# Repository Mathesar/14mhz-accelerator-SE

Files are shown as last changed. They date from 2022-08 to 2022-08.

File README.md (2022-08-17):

# 14mhz-accelerator-SE
Special Edition of the 14MHz accelerator without local fastram and support for DMA masters

This version was especially created for owners of SCSI sidecars like the A590. 
It should support the DMA transfers of these sidecars.
This version also does away with the local 14MHz FAST RAM to reduce cost. 
Finally, this version uses the DIP version 68000 so one can retry overclocking the original CPU to make the design even cheaper.

IMPORTANT NOTE:
This design is UNTESTED AT THIS POINT. Use entirely at your own risk and have fun while doing so!

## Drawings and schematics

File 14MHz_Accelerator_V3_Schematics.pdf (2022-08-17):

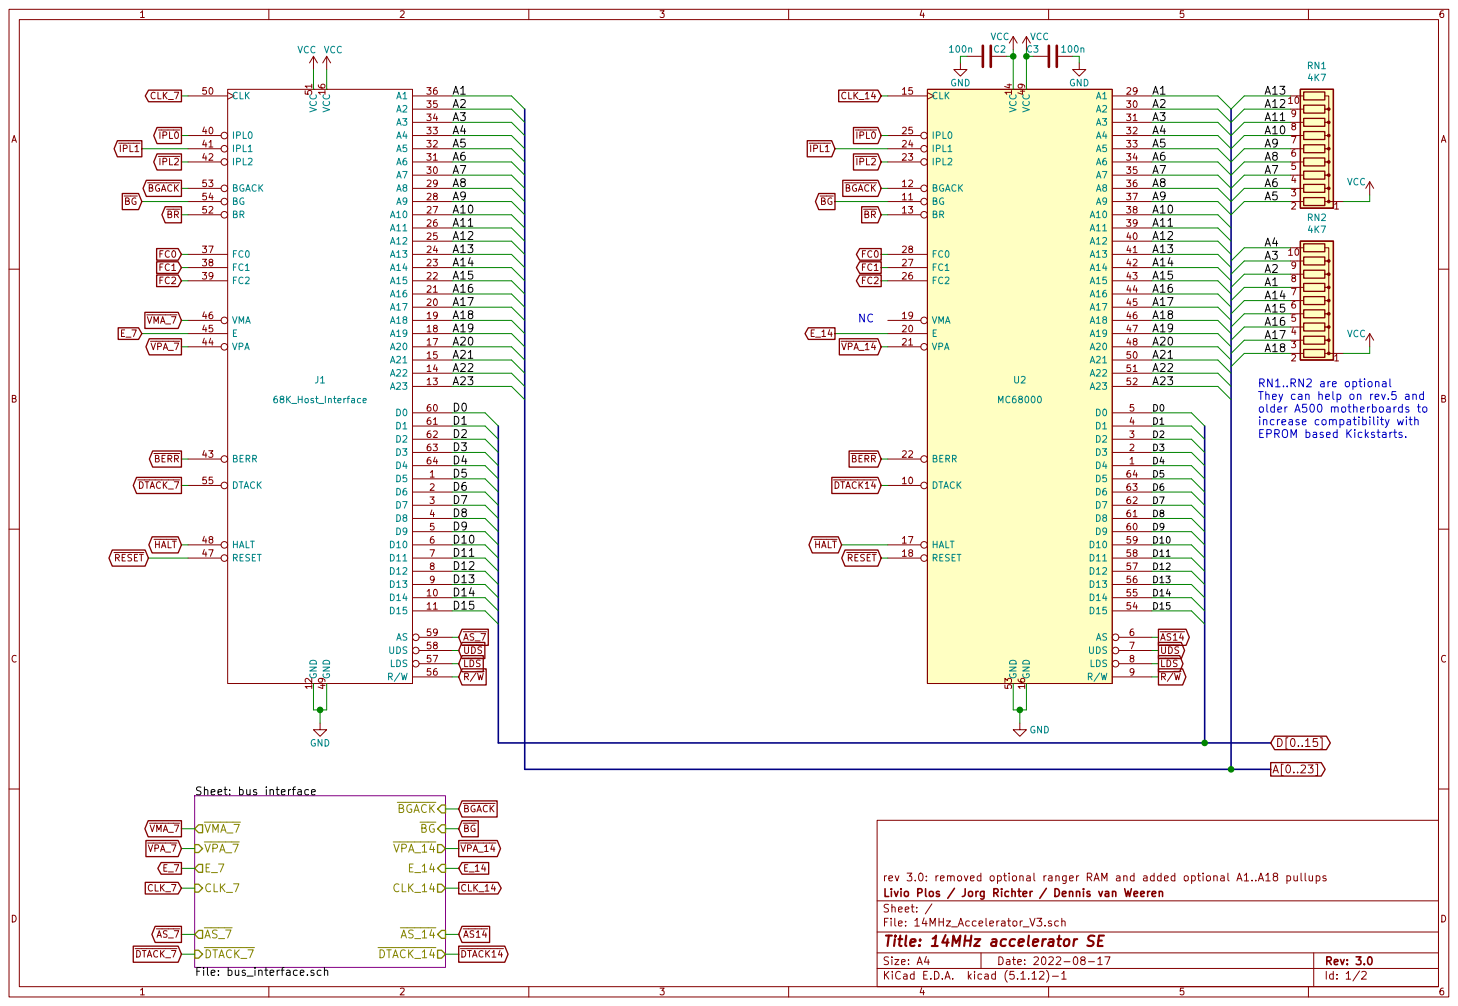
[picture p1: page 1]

RN1..RN2 are optional
They can help on rev.5 and older A500 motherboards to

rev 3.0: removed optional ranger RAM and added optional A1..A18 pullups
File: 14MHz_Accelerator_V3.sch Sheet: / Livio Plos / Jorg Richter / Dennis van Weeren

Id: 1/2 Title: 14MHz accelerator SE

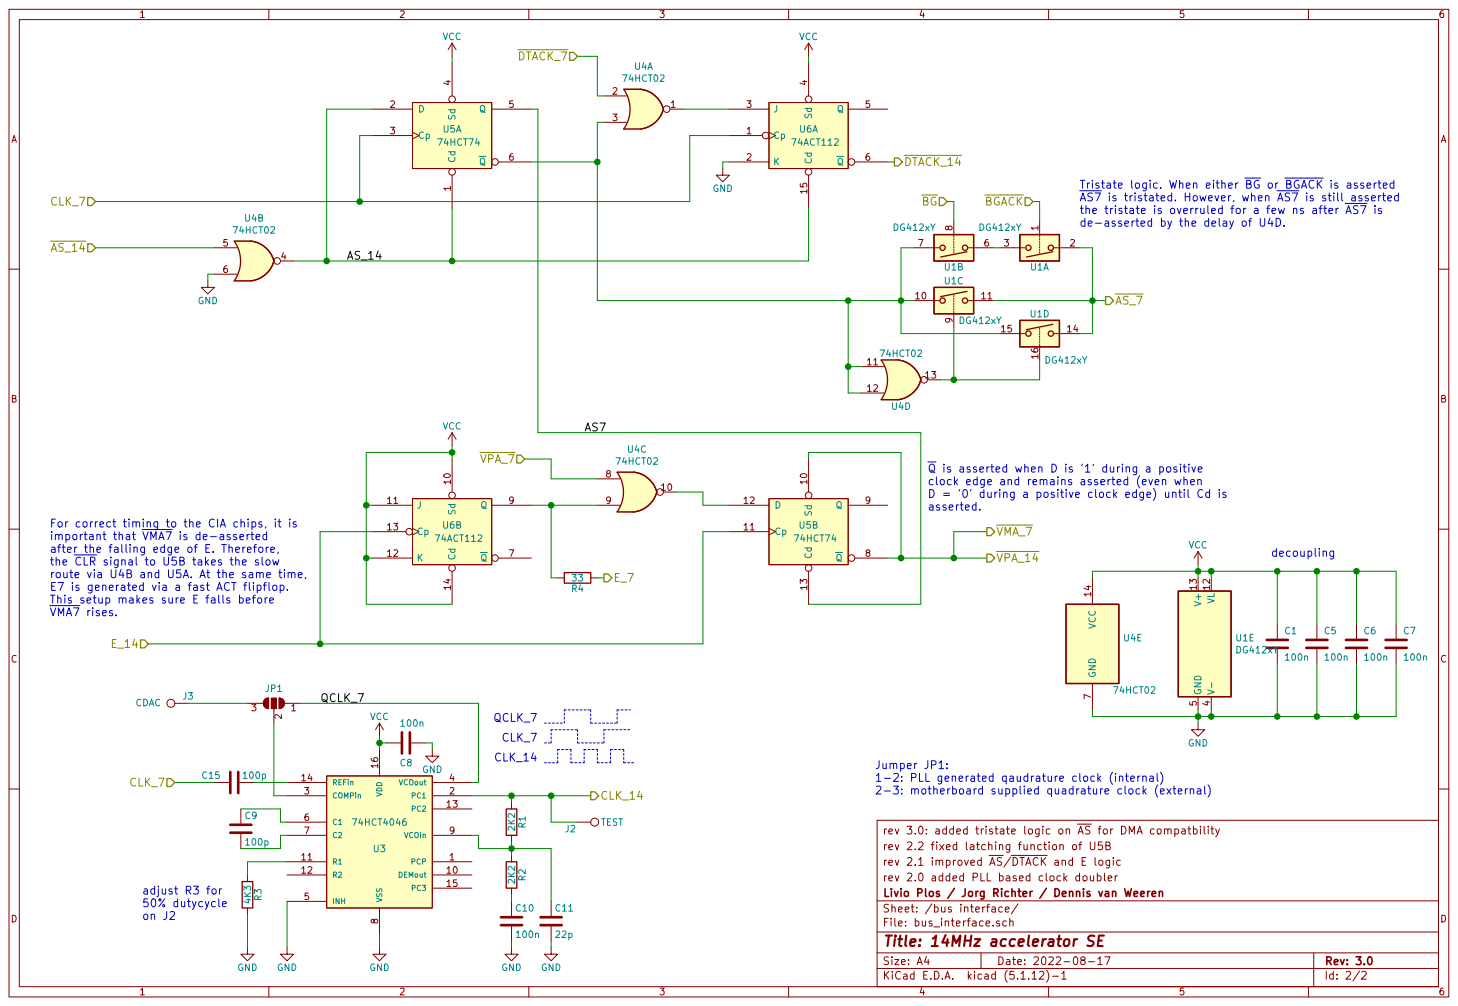
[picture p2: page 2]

Tristate logic. When either BG or BGACK is asserted
AS7 is tristated. However, when AS7 is still asserted
the tristate is overruled for a few ns after AS7 is
de-asserted by the delay of U4D.

Q is asserted when D is '1' during a positive
clock edge and remains asserted (even when
D = '0' during a positive clock edge) until Cd is asserted.

For correct timing to the CIA chips, it is
important that VMA7 is de-asserted
after the falling edge of E. Therefore,
the CLR signal to U5B takes the slow
route via U4B and U5A. At the same time,
E7 is generated via a fast ACT flipflop.

Jumper JP1:
1-2: PLL generated qaudrature clock (internal)
2-3: motherboard supplied quadrature clock (external)

rev 2.2 fixed latching function of U5B
rev 2.1 improved AS/DTACK and E logic
rev 2.0 added PLL based clock doubler
File: bus_interface.sch Sheet: /bus interface/ Livio Plos / Jorg Richter / Dennis van Weeren

Id: 2/2 Title: 14MHz accelerator SE

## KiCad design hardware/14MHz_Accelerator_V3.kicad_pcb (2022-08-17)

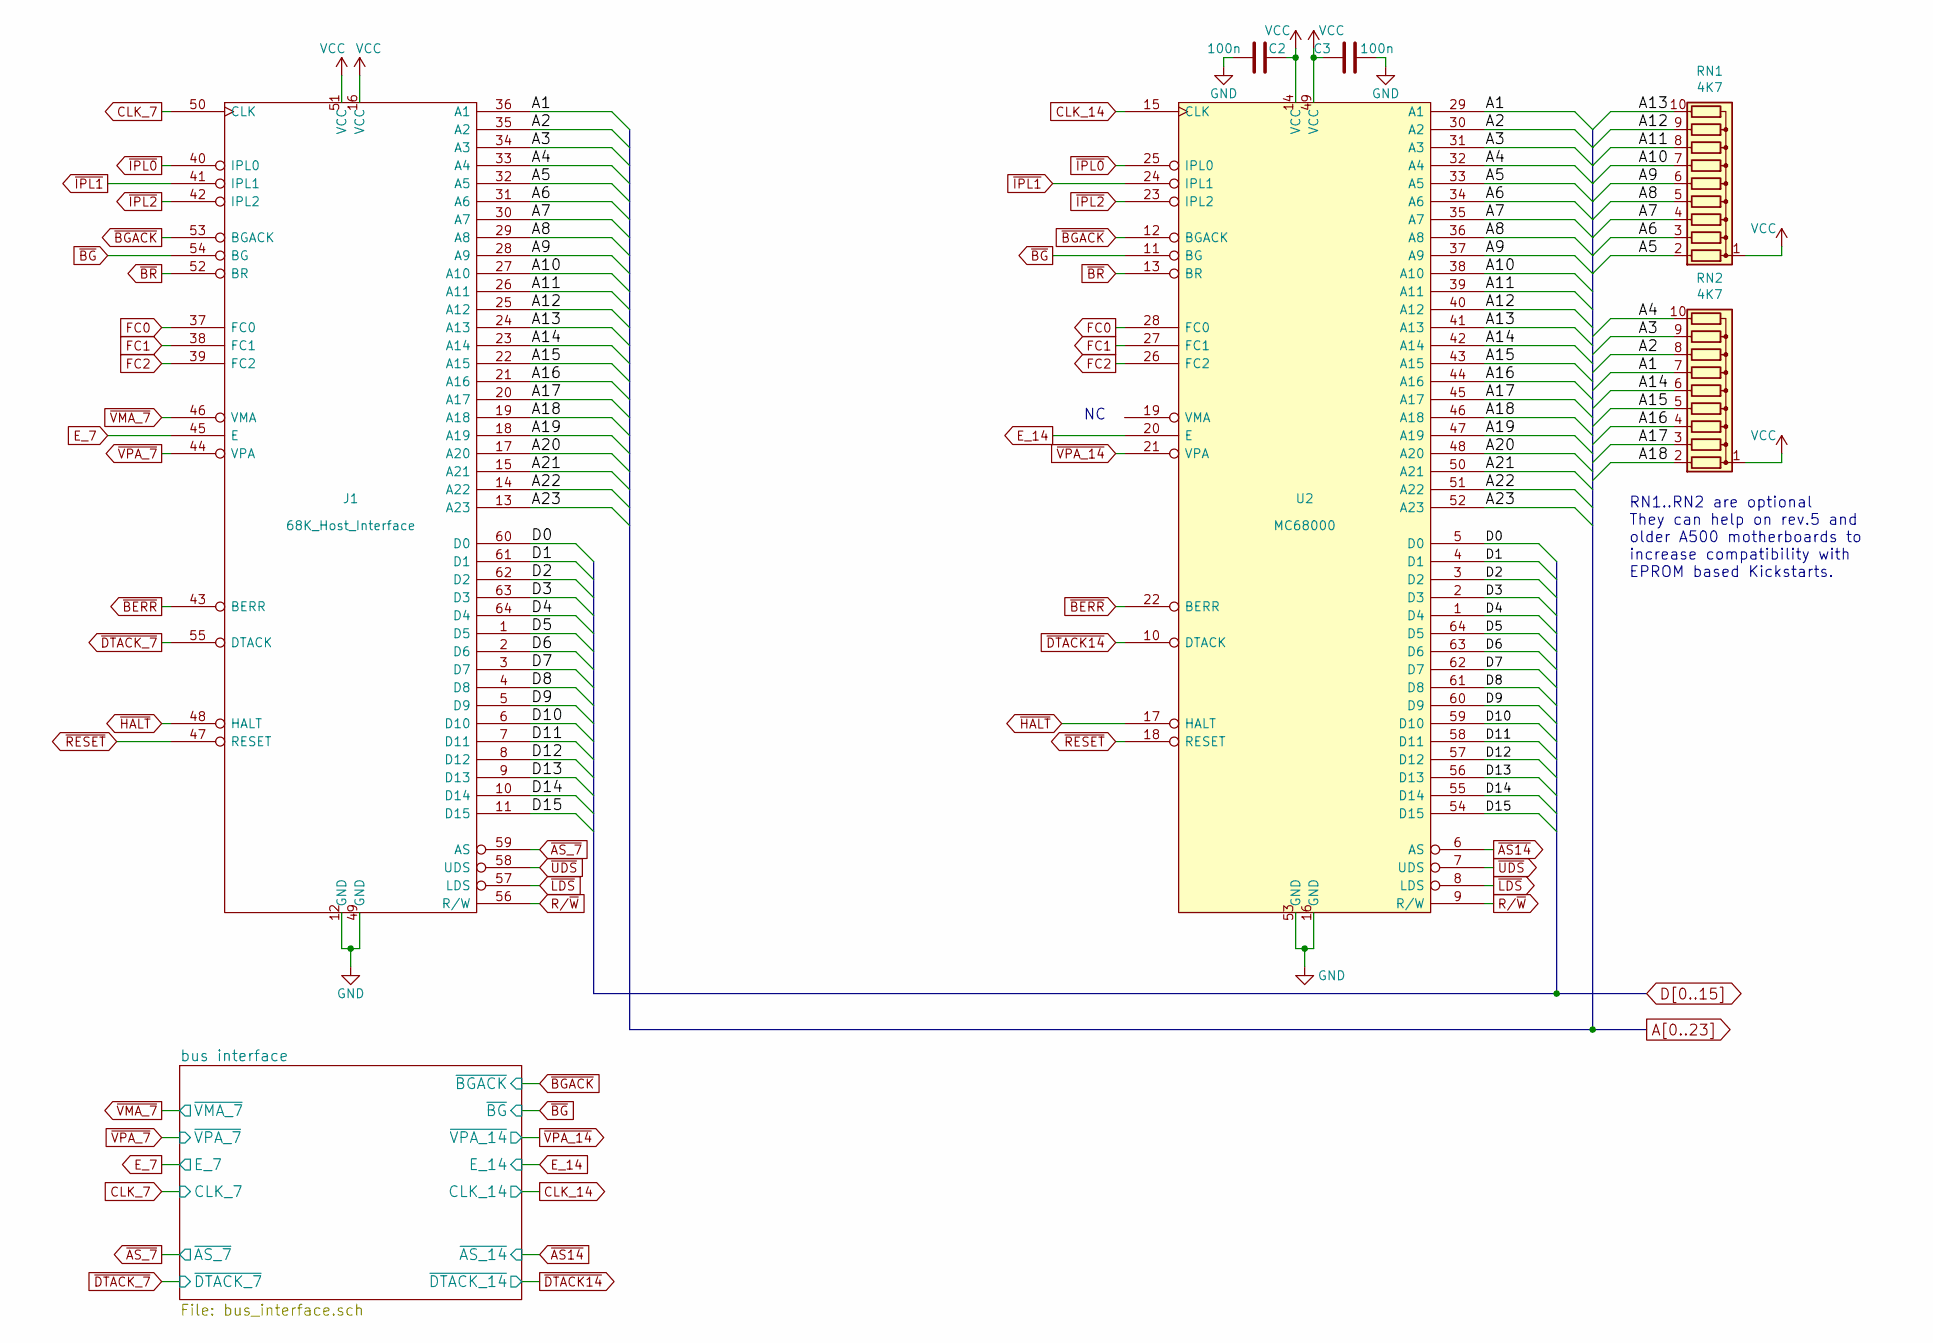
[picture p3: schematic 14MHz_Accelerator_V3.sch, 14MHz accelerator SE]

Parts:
C2, C3: 100n; C_0805_HandSoldering
J1: 68K_Host_Interface; DIP-64_W22.86mm
RN1, RN2: 4K7; R_Array_SIP10
U2: MC68000; DIP-64_W22.86mm

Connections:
A1: J1.36 (A1), RN2.7 (R6), U2.29 (A1)
A2: J1.35 (A2), RN2.8 (R7), U2.30 (A2)
A3: J1.34 (A3), RN2.9 (R8), U2.31 (A3)
A4: J1.33 (A4), RN2.10 (R9), U2.32 (A4)
A5: J1.32 (A5), RN1.2 (R1), U2.33 (A5)
A6: J1.31 (A6), RN1.3 (R2), U2.34 (A6)
A7: J1.30 (A7), RN1.4 (R3), U2.35 (A7)
A8: J1.29 (A8), RN1.5 (R4), U2.36 (A8)
A9: J1.28 (A9), RN1.6 (R5), U2.37 (A9)
A10: J1.27 (A10), RN1.7 (R6), U2.38 (A10)
A11: J1.26 (A11), RN1.8 (R7), U2.39 (A11)
A12: J1.25 (A12), RN1.9 (R8), U2.40 (A12)
A13: J1.24 (A13), RN1.10 (R9), U2.41 (A13)
A14: J1.23 (A14), RN2.6 (R5), U2.42 (A14)
A15: J1.22 (A15), RN2.5 (R4), U2.43 (A15)
A16: J1.21 (A16), RN2.4 (R3), U2.44 (A16)
A17: J1.20 (A17), RN2.3 (R2), U2.45 (A17)
A18: J1.19 (A18), RN2.2 (R1), U2.46 (A18)
A19: J1.18 (A19), U2.47 (A19)
A20: J1.17 (A20), U2.48 (A20)
A21: J1.15 (A21), U2.50 (A21)
A22: J1.14 (A22), U2.51 (A22)
A23: J1.13 (A23), U2.52 (A23)
CLK_7: J1.50 (CLK); also elsewhere on the board
CLK_14: U2.15 (CLK); also elsewhere on the board
D0: J1.60 (D0), U2.5 (D0)
D1: J1.61 (D1), U2.4 (D1)
D2: J1.62 (D2), U2.3 (D2)
D3: J1.63 (D3), U2.2 (D3)
D4: J1.64 (D4), U2.1 (D4)
D5: J1.1 (D5), U2.64 (D5)
D6: J1.2 (D6), U2.63 (D6)
D7: J1.3 (D7), U2.62 (D7)
D8: J1.4 (D8), U2.61 (D8)
D9: J1.5 (D9), U2.60 (D9)
D10: J1.6 (D10), U2.59 (D10)
D11: J1.7 (D11), U2.58 (D11)
D12: J1.8 (D12), U2.57 (D12)
D13: J1.9 (D13), U2.56 (D13)
D14: J1.10 (D14), U2.55 (D14)
D15: J1.11 (D15), U2.54 (D15)
E_7: J1.45 (E); also elsewhere on the board
E_14: U2.20 (E); also elsewhere on the board
FC0: J1.37 (FC0), U2.28 (FC0)
FC1: J1.38 (FC1), U2.27 (FC1)
FC2: J1.39 (FC2), U2.26 (FC2)
GND: C2.1, C3.2, J1.12 (GND), J1.49 (GND), U2.16 (GND), U2.53 (GND); also elsewhere on the board
R/~W: J1.56 (R/W), U2.9 (R/W)
VCC: C2.2, C3.1, J1.16 (VCC), J1.51 (VCC), RN1.1 (common), RN2.1 (common), U2.14 (VCC), U2.49 (VCC); also elsewhere on the board
~AS14: U2.6 (AS); also elsewhere on the board
~AS_7: J1.59 (AS); also elsewhere on the board
~BERR~: J1.43 (BERR), U2.22 (BERR)
~BGACK~: J1.53 (BGACK), U2.12 (BGACK); also elsewhere on the board
~BG~: J1.54 (BG), U2.11 (BG); also elsewhere on the board
~BR~: J1.52 (BR), U2.13 (BR)
~DTACK14: U2.10 (DTACK); also elsewhere on the board
~DTACK_7: J1.55 (DTACK); also elsewhere on the board
~HALT~: J1.48 (HALT), U2.17 (HALT)
~IPL0~: J1.40 (IPL0), U2.25 (IPL0)
~IPL1~: J1.41 (IPL1), U2.24 (IPL1)
~IPL2~: J1.42 (IPL2), U2.23 (IPL2)
~LDS: J1.57 (LDS), U2.8 (LDS)
~RESET~: J1.47 (RESET), U2.18 (RESET)
~UDS: J1.58 (UDS), U2.7 (UDS)
~VMA_7: J1.46 (VMA), U2.21 (VPA); also elsewhere on the board
~VPA_7: J1.44 (VPA); also elsewhere on the board

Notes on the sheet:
RN1..RN2 are optional They can help on rev.5 and older A500 motherboards to increase compatibility with EPROM based Kickstarts.

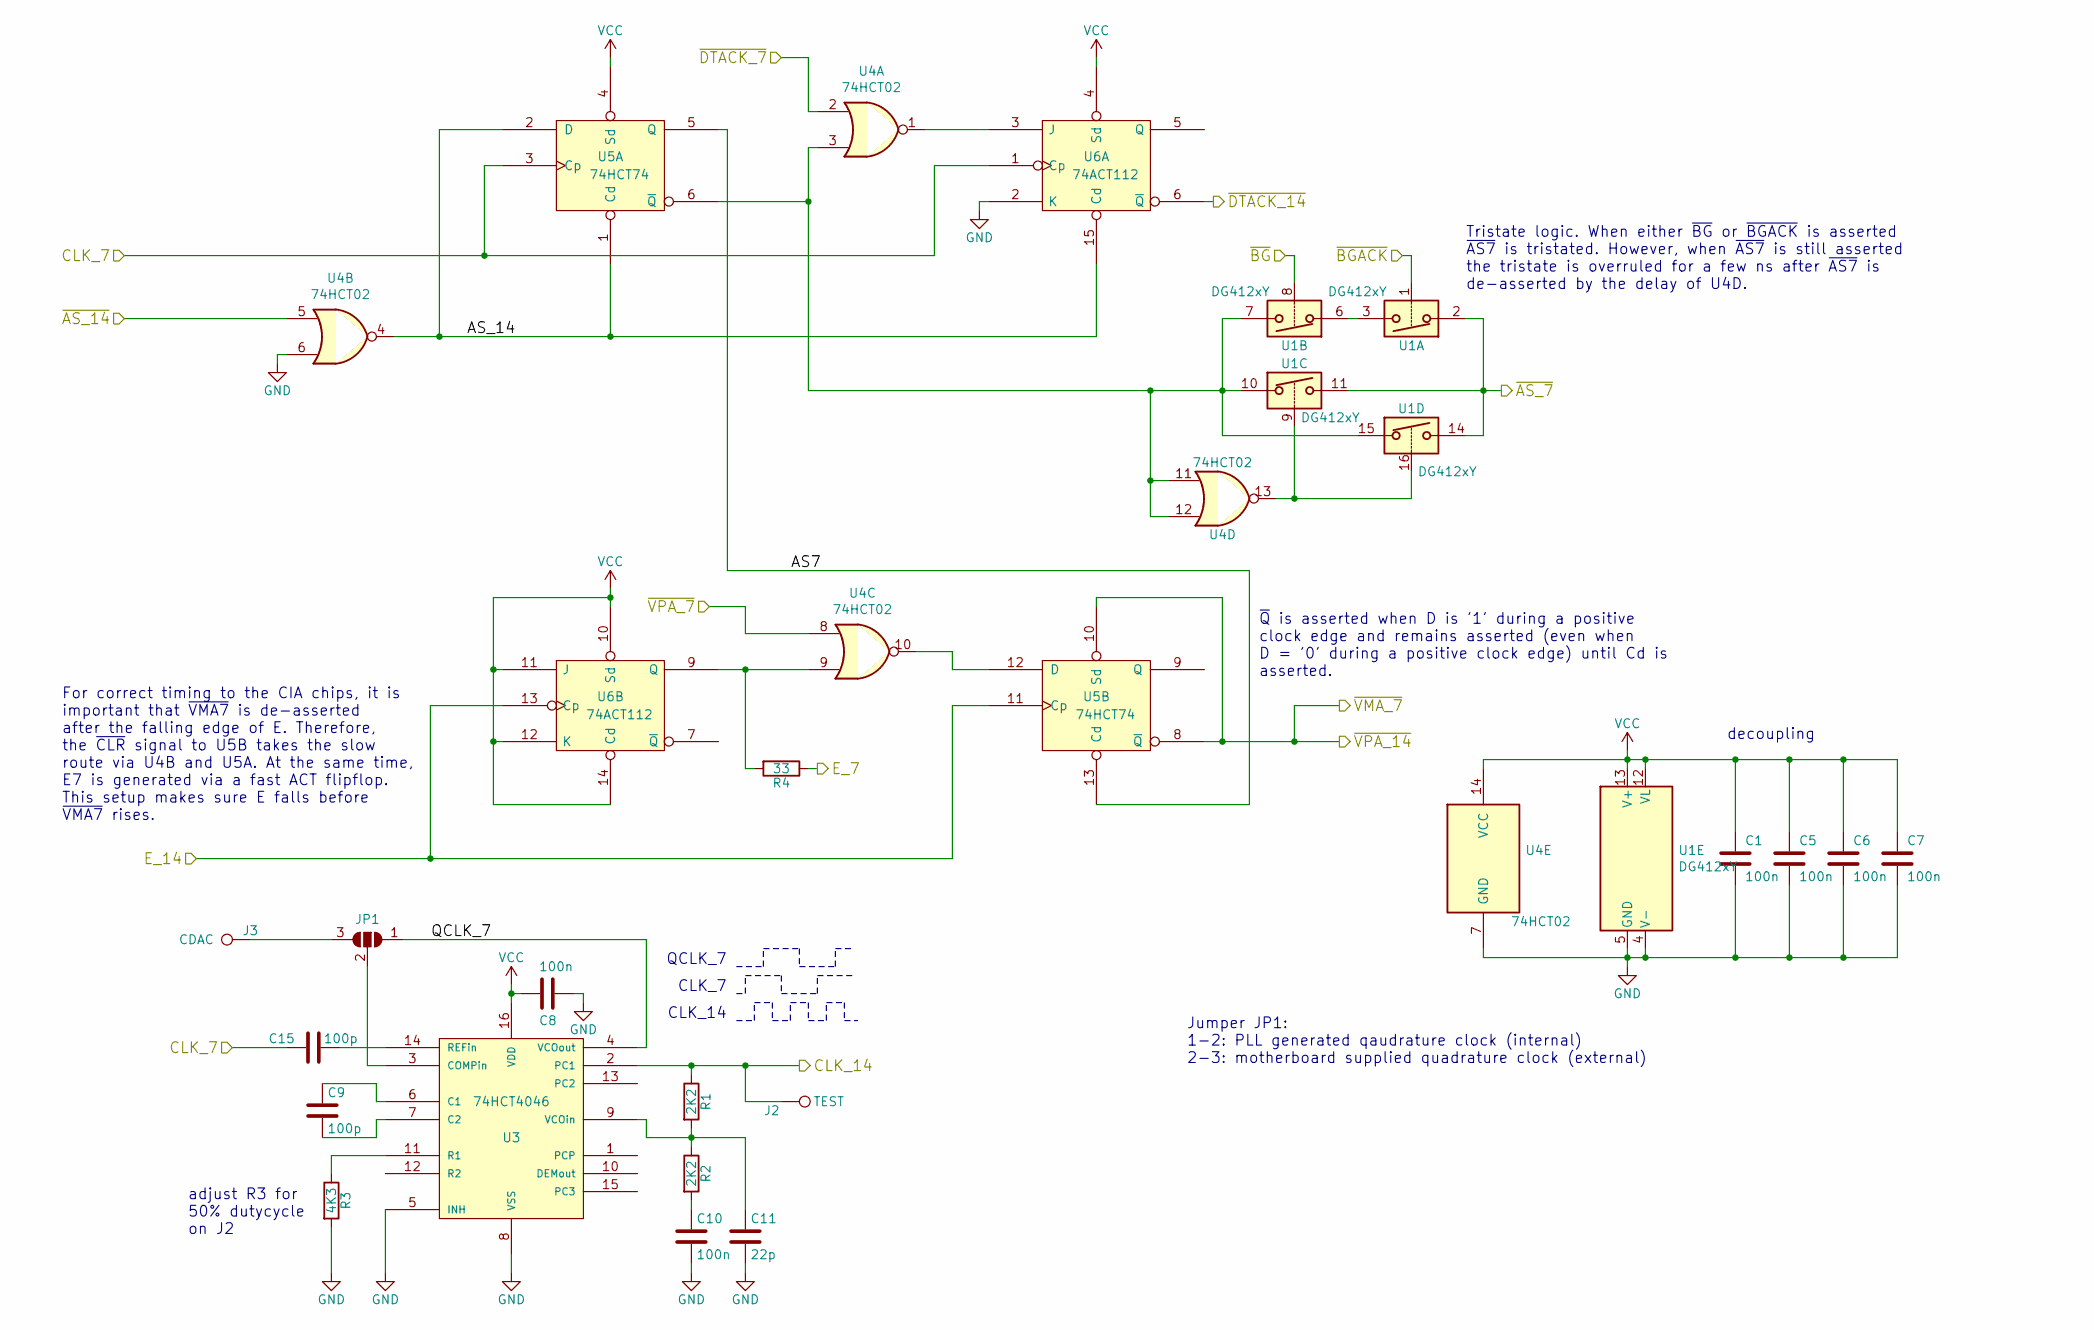
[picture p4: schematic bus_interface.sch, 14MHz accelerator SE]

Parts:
C1, C5, C6, C7, C8, C10: 100n; C_0805_HandSoldering
C9, C15: 100p; C_0805_HandSoldering
C11: 22p; C_0805_HandSoldering
J2: TEST; Pin_d1.0mm_L10.0mm
J3: CDAC; Pin_d1.0mm_L10.0mm
JP1: SolderJumper_3_Open; GS3
R1, R2: 2K2; R_0805_HandSoldering
R3: 4K3; R_0805_HandSoldering
R4: 33; R_0805_HandSoldering
U1: DG412xY; SOIC-16_3.9x9.9mm_P1.27mm
U3: 74HCT4046; SOIC-16_3.9x9.9mm_Pitch1.27mm
U4: 74HCT02; SOIC-14_3.9x8.7mm_Pitch1.27mm
U5: 74HCT74; SOIC-14_3.9x8.7mm_Pitch1.27mm
U6: 74ACT112; SOIC-16_3.9x9.9mm_Pitch1.27mm

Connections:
/bus interface/AS7: U5.5 (Q), U5.13 (Cd)
/bus interface/AS_14: U4.4, U5.1 (Cd), U5.2 (D), U6.15 (Cd)
/bus interface/QCLK_7: JP1.1 (A), U3.4 (VCOout)
CLK_7: C15.1, U5.3 (Cp), U6.1 (Cp); also elsewhere on the board
CLK_14: J2.1, R1.1, U3.2 (PC1); also elsewhere on the board
E_7: R4.1; also elsewhere on the board
E_14: U5.11 (Cp), U6.13 (Cp); also elsewhere on the board
GND: C1.2, C5.2, C6.2, C7.2, C8.1, C10.2, C11.2, R3.2, U1.4 (V-), U1.5 (GND), U3.5 (INH), U3.8 (VSS), U4.6, U4.7 (GND), U5.7 (GND), U6.2 (K), U6.8 (GND); also elsewhere on the board
unnamed: C9.1, U3.6 (C1)
unnamed: C9.2, U3.7 (C2)
unnamed: C10.1, R2.2
unnamed: C11.1, R1.2, R2.1, U3.9 (VCOin)
unnamed: C15.2, U3.14 (REFin)
unnamed: J3.1, JP1.3 (B)
unnamed: JP1.2 (C), U3.3 (COMPin)
unnamed: R3.1, U3.11 (R1)
unnamed: R4.2, U4.9, U6.9 (Q)
unnamed: U1.3, U1.6
unnamed: U1.7, U1.10, U1.15, U4.3, U4.11, U4.12, U5.6 (~Q)
unnamed: U1.9, U1.16, U4.13
unnamed: U4.1, U6.3 (J)
unnamed: U4.10, U5.12 (D)
VCC: C1.1, C5.1, C6.1, C7.1, C8.2, U1.12 (VL), U1.13 (V+), U3.16 (VDD), U4.14 (VCC), U5.4 (Sd), U5.14 (VCC), U6.4 (Sd), U6.10 (Sd), U6.11 (J), U6.12 (K), U6.14 (Cd), U6.16 (VCC); also elsewhere on the board
~AS14: U4.5; also elsewhere on the board
~AS_7: U1.2, U1.11, U1.14; also elsewhere on the board
~BGACK~: U1.1; also elsewhere on the board
~BG~: U1.8; also elsewhere on the board
~DTACK14: U6.6 (~Q); also elsewhere on the board
~DTACK_7: U4.2; also elsewhere on the board
~VMA_7: U5.8 (~Q), U5.10 (Sd); also elsewhere on the board
~VPA_7: U4.8; also elsewhere on the board

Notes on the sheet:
CLK_7
CLK_14
QCLK_7
adjust R3 for 50% dutycycle on J2
~Q~ is asserted when D is '1' during a positive clock edge and remains asserted (even when D = '0' during a positive clock edge) until Cd is asserted.
Jumper JP1: 1-2: PLL generated qaudrature clock (internal) 2-3: motherboard supplied quadrature clock (external)
For correct timing to the CIA chips, it is important that ~VMA7~ is de-asserted after the falling edge of E. Therefore, the ~CLR~ signal to U5B takes the slow route via U4B and U5A. At the same time, E7 is generated via a fast ACT flipflop. This setup makes sure E falls before ~VMA7~ rises.
Tristate logic. When either ~BG~ or ~BGACK~ is asserted ~AS7~ is tristated. However, when ~AS7~ is still asserted the tristate is overruled for a few ns after ~AS7~ is de-asserted by the delay of U4D.
decoupling

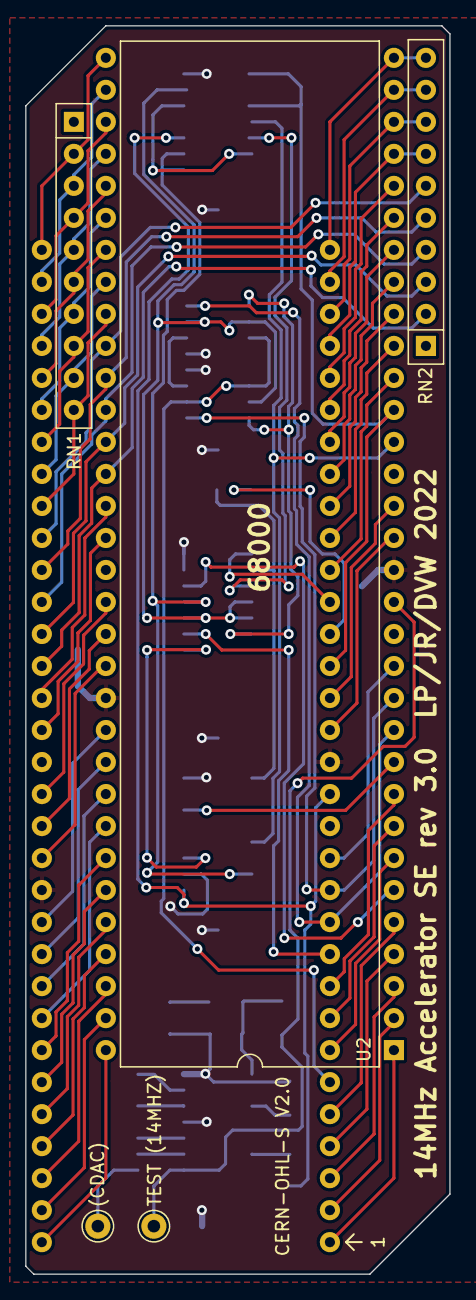
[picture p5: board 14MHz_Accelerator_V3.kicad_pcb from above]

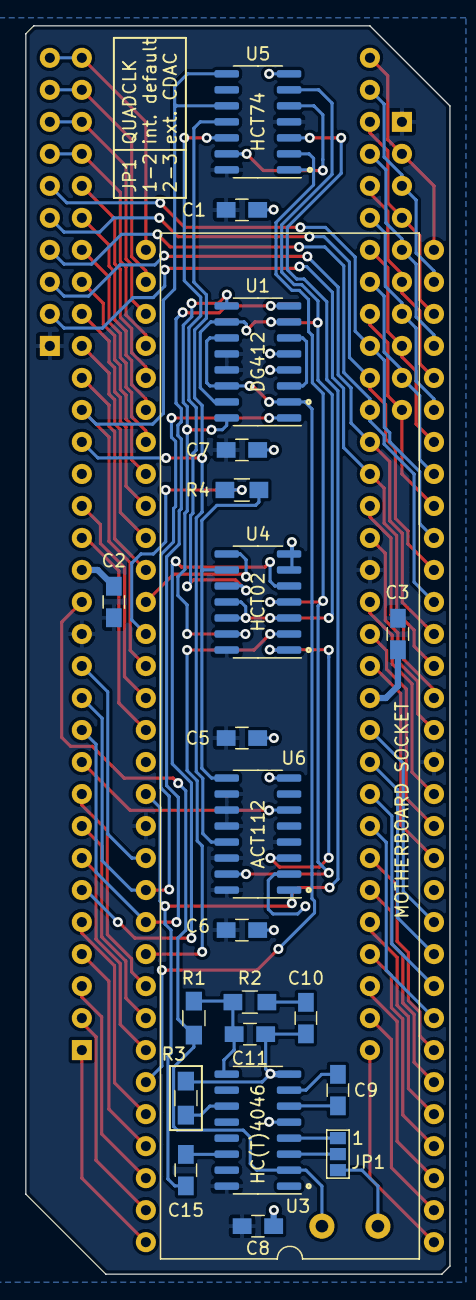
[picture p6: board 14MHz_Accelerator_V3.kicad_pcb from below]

Board: 2 copper layers, 33.7 x 99.1 mm, 27 parts (22 on the bottom side), 83 nets.

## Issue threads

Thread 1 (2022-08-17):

Needs testing

Mathesar, 2022-08-17:
This design is not tested

bkodenkt, 2022-09-12:
I'd love to test the board, but I don't really know where to start, i.e. I have zero experience in ordering pcb's or soldering smd parts. Should somebody start solderng prototypes, I am willing to help testing the device and, of course, I will support financing the first prototype batch substantially.

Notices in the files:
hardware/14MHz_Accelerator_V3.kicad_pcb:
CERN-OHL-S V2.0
